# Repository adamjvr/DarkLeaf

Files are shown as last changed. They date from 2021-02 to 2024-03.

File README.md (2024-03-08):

# DarkLeaf
Adafruit Feather style board for the STM32WB5MMGH6TR 2G RF Module

Quick Specs:
- STM32WB5MMGH6TR 2G RF Module
- Adafruit Feather pinout and formfactor
- ARM Cortex M Debug Port
- USB C Connector For DFU Flashing (USB 2.0 interface)
- LiPO powered w/ onboard 3.3V LDO Regulator
- Can be powered directly by 3.3V when breadboarded

KiCAD 2D PCB Render 
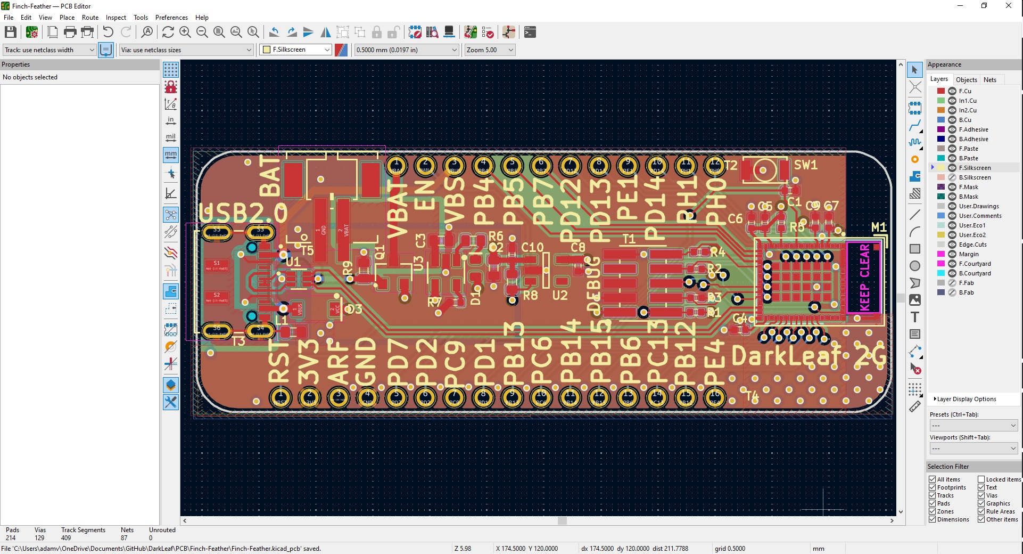
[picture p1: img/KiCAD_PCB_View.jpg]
PCB Render


3D KiCAD PCB Renders 
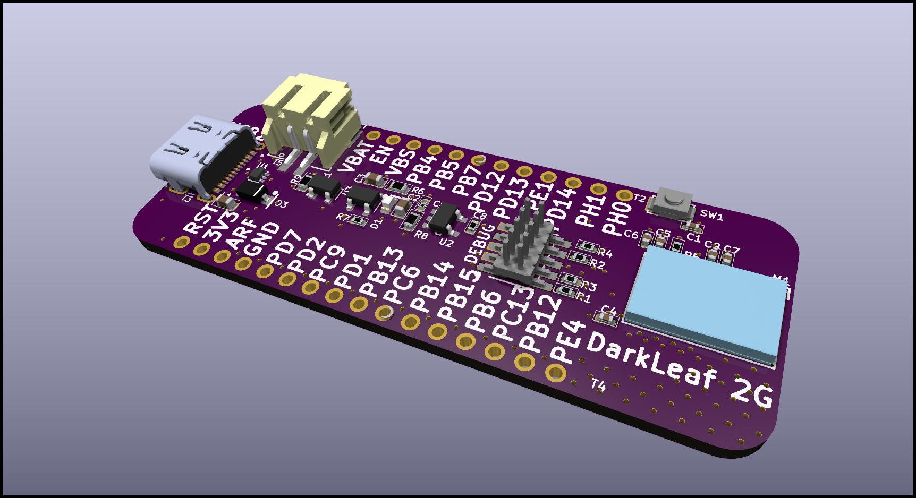
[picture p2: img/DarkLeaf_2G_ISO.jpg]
ISO Render


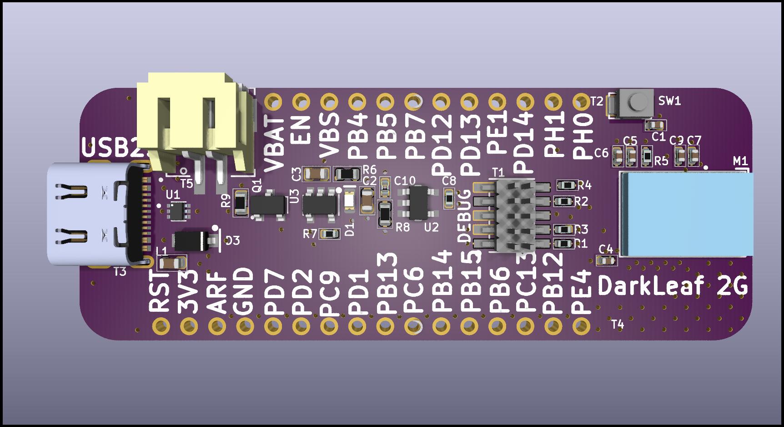
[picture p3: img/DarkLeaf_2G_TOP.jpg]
Top Render


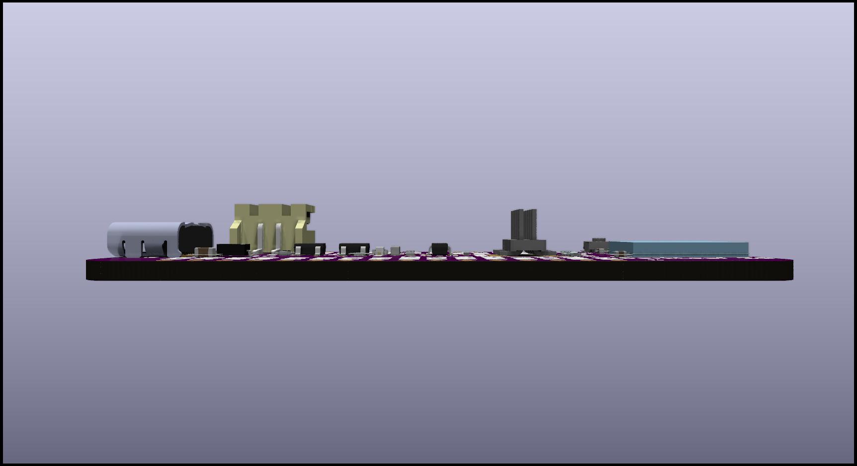
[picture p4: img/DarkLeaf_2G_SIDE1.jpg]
Side Render


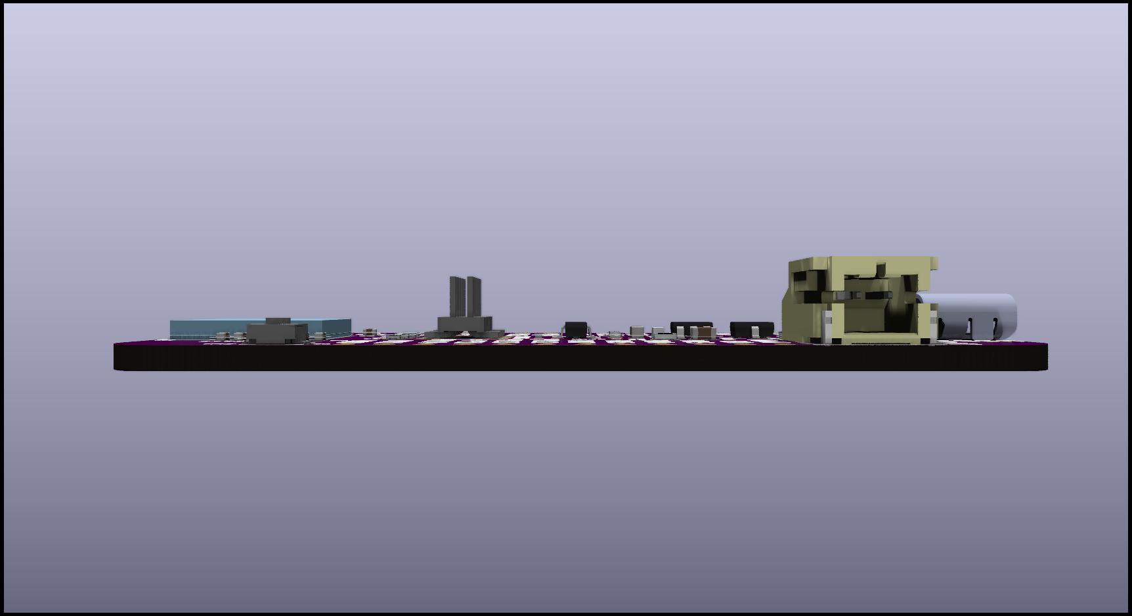
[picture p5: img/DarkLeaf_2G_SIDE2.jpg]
Side Render


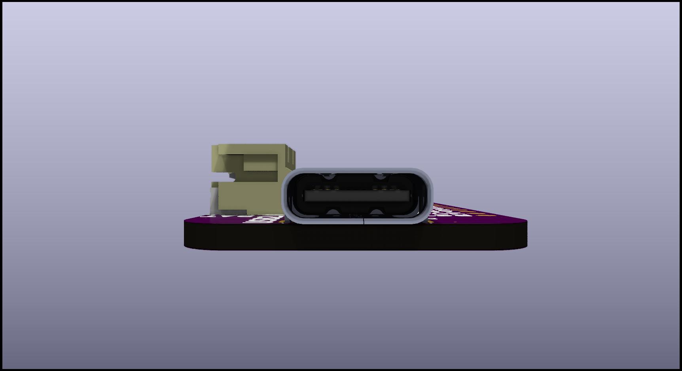
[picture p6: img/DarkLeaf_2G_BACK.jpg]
Back Render


Prototype made by OSHPark.com 
OSHPARK Fab}

Released Under CERN Open Hardware License Version 2

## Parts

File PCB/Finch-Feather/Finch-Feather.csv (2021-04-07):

Reference | Quantity | Value | Footprint | Datasheet | Cost QTY: 1 | Cost QTY: 1000 | Cost QTY: 10000 | Cost QTY: 2500 | Cost QTY: 5000 | Date Created | Date Modified | Description | Designer | Height | Lead-Free ? | MFR | MFR# | Management_ID | Mounting | Package | Pin Count # | RoHS Levels | Status | Tolerance | Type | Vendor | Vendor # | Voltage | _Value_
C1 C4 C5 C6 C7 C8 C9 C10 | 8 | C0402C104K9PACTU | AVR-KiCAD-Lib-Resistors:R0402 | https://content.kemet.com/datasheets/KEM_C1006_X5R_SMD.pdf | 0.10000 | 0.01139 | 0.00756 | 0.01035 | 0.00952 | 12/7/2019 | 12/7/2019 | 0.1µF ±10% 6.3V Ceramic Capacitor X5R 0402 (1005 Metric) | AVR | 0.55mm | Yes | KEMET | C0402C104K9PACTU | * | SMT | 0402 | 2 | 1 | Active | 10% | Ceramic Cap | Digikey | 399-3026-6-ND | 6.3V | 0.1uF
C2 C3 | 2 | C0603C475K9PACTU | AVR-KiCAD-Lib-Capacitors:C0603 | https://content.kemet.com/datasheets/KEM_C1006_X5R_SMD.pdf | 0.17000 | 0.03280 | 0.02260 | * | 0.02430 | 12/6/2019 | 12/6/2019 | 4.7µF ±10% 6.3V Ceramic Capacitor X5R 0603 (1608 Metric) | AVR | 0.9mm | Yes | KEMET | C0603C475K9PACTU | * | SMT | 0603 | 2 | 1 | Active | 10% | Ceramic Cap | Digikey | 399-3482-1-ND | 6.3V | 4.7uF X5R
D1 | 1 | LTST-C194TBKT | AVR-KiCAD-Lib-Diodes:LED0603 | http://optoelectronics.liteon.com/upload/download/DS22-2010-0025/LTST-C194TBKT.PDF | 0.42000 | 0.07797 | 0.05424 | * | 0.06102 | 3/1/2020 | 3/1/2020 | Blue 468nm LED Indication - Discrete 3.3V 0603 (1608 Metric) | AVR | 0.45mm | Yes | Lite-On Inc. | LTST-C194TBKT | * | SMT | 0603 | 2 | 1 | Active | * | Blue LED Colorless | Digikey | 160-1837-2-ND | 3.3V | Blue LED
D3 | 1 | MBR0540T1G | AVR-KiCAD-Lib-Diodes:D_SOD-123 | https://www.onsemi.com/pub/Collateral/MBR0540T1-D.PDF | 0.37000 | 0.07191 | * | * | * | 7/31/2020 | 7/31/2020 | Diode Schottky 40V 500mA Surface Mount SOD-123 | AVR | 1.17mm | Yes | ON Semiconductor | MBR0540T1G | * | SMT | SOD-123 | 2 | 1 | Active | * | TVS Diode | Digikey | MBR0540T1GOSTR-ND | 40V | MBR0540T1G
H1 H2 H4 | 3 | 2.54mm_PLT_Hole | AVR-KiCAD-Lib-Holes_Fasteners:2.54mm_PLT_Hole |  | * | * | * | * | * | * | * | * | * | * | * | * | * | * | * | * | * | * | * | * | * | * | * | * | 2.54mm Hole
L1 | 1 | MI0603K300R-10 | AVR-KiCAD-Lib-Inductors:MI0603K300R-10 | https://www.laird.com/sites/default/files/2018-11/Catalog_EMI%20FILTERING%20RF%200717.pdf | 0.16000 | 0.04313 | * | * | * | 6/16/2020 | 6/16/2020 | 30 Ohms @ 100MHz 1 Power Line Ferrite Bead 0603 (1608 Metric) 1.5A 90mOhm | AVR | 0.95mm | Yes | Laird-Signal Integrity Products | MI0603K300R-10 | * | SMT | 0603 | 2 | 1 | Active | * | Ferrite Bead | Digikey | 240-2373-1-ND | * | MI0603K300R-10
M1 | 1 | STM32WB5MMGH6TR | AVR-KiCAD-Lib-Modules:STM32WB5MMGH6TR | https://www.st.com/resource/en/datasheet/stm32wb5mmg.pdf | 12.98000 | 9.01250 | * | * | * | 2/8/2021 | 2/8/2021 | 802.15.4, Bluetooth Bluetooth v5.0, Thread, Zigbee® Transceiver Module 2.4GHz Integrated, Chip Surface Mount | AVR | 1.382mm | Yes | STMicroelectronics | STM32WB5MMGH6TR | * | SMT | * | 86 | 1 | Active | * | RF and MCU Integrated Module | Digikey | 497-STM32WB5MMGH6TR-ND | 1.71-3.6V | STM32WB5MMGH6TR
Q1 | 1 | DMP3125L-7 | growbox-KiCAD-Transistors:SOT-23 | https://www.diodes.com/assets/Datasheets/DMP3125L.pdf | 0.46000 | 0.09759 | 0.07624 | * | 0.08324 | 3/1/2020 | 3/1/2020 | P-Channel 30V 2.5A (Ta) 650mW (Ta) Surface Mount SOT-23 | AVR | 1.10mm | Yes | Diodes Incorporated | DMP3125L-7 | * | SMT | SOT23 | 3 | 1 | Active | * | P-Channel MOSFET | Digikey | DMP3125L-7DICT-ND | 20V | DMP3125L-7
R1 R2 R3 R4 R5 | 5 | RC0402FR-0710KL | AVR-KiCAD-Lib-Resistors:R0402 | https://www.yageo.com/upload/media/product/productsearch/datasheet/rchip/PYu-RC_Group_51_RoHS_L_10.pdf | 0.10000 | 0.00289 | * | 0.00251 | 0.00207 | 12/11/2019 | 12/11/2019 | 10 kOhms ±1% 0.063W, 1/16W Chip Resistor 0402 (1005 Metric) Moisture Resistant Thick Film | AVR | 0.4mm | Yes | Yageo | RC0402FR-0710KL | * | SMT | 0402 | 2 | 1 | Active | 1% | Thick FIlm Resistor | Digikey | 311-10.0KLRCT-ND | * | 10K
R6 | 1 | RC0603FR-07470RL | AVR-KiCAD-Lib-Resistors:R0603 |  | 0.100 | 0.00476 | * | 0.00418 | * | 4/23/2019 | 4/23/2019 | RES SMD 470 OHM 1% 1/10W 0603 | AVR | 0.55mm | Yes | Yageo | RC0603FR-07470RL | * | SMT | 0603 | 2 | 1 | Active | 1% | SMT Chip Resistor | Digikey | 311-470HRCT-ND | * | 470r
R7 | 1 | RC0402FR-072KL | AVR-KiCAD-Lib-Resistors:R0402 | https://www.yageo.com/upload/media/product/productsearch/datasheet/rchip/PYu-RC_Group_51_RoHS_L_10.pdf | 0.10000 | 0.00289 | 0.00163 | 0.00251 | 0.00207 | 7/6/2020 | 7/6/2020 | 2 kOhms ±1% 0.063W, 1/16W Chip Resistor 0402 (1005 Metric) Moisture Resistant Thick Film | AVR | 0.4mm | Yes | Yageo | RC0402FR-072KL | * | SMT | 0402 | 2 | 1 | Active | 1% | Resistor | Digikey | 311-2KLRCT-ND | * | 2K
R8 R9 | 2 | RC0603FR-07100KL | AVR-KiCAD-Lib-Resistors:R0603 |  | 0.10 | 0.00476 | * | 0.00418 | * | 4/23/2019 | 4/23/2019 | RES SMD 100K OHM 1% 1/10W 0603 | AVR | 0.55mm | Yes | Yageo | RC0603FR-07100KL | * | SMT | 0603 | 2 | 1 | Active | 1% | SMT Chip Resistor | Digikey | 311-100KHRCT-ND | * | 100K
SW1 | 1 | B3U-1000P | AVR-KiCAD-Lib-Mech-Switches:B3U-1000P | https://omronfs.omron.com/en_US/ecb/products/pdf/en-b3u.pdf | 0.98000 | 0.59822 | * | * | * | 6/15/2020 | 6/15/2020 | Tactile Switch SPST-NO Top Actuated Surface Mount | AVR | 1.6mm | Yes | Omron Electronics Inc-EMC Div | B3U-1000P | * | SMT | Proprietary | 2 | 1 | Active | * | Switch | Digikey | SW1020CT-ND | * | B3U-1000P
T1 | 1 | 20021121-00010C4LF | AVR-KiCAD-Lib-Connectors:20021121-00010C4LF | https://cdn.amphenol-icc.com/media/wysiwyg/files/drawing/20021121.pdf | 0.87000 | * | * | * | * | 6/16/2020 | 6/16/2020 | CONN HEADER SMD 10POS 1.27MM | AVR | 5.5mm | Yes | Amphenol ICC (FCI) | 20021121-00010C4LF | * | SMT | * | 10 | 1 | Active | * | SMT Pin Header | Digikey | 609-3695-1-ND | * | 20021121-00010C4LF
T2 | 1 | TSW-112-07-G-S | AVR-KiCAD-Lib-Connectors:SAMTEC-TSW-112-07-X-S | http://suddendocs.samtec.com/catalog_english/tsw_th.pdf | 1.29000 | * | * | * | * | 2/13/2021 | 2/13/2021 | Connector Header Through Hole 12 position 0.100 (2.54mm)" | AVR | 11.8mm | Yes | Samtec Inc. | TSW-112-07-G-S | * | ThroughHole | * | 12 | 1 | Active | * | Pin Header | Digikey | SAM1029-12-ND | * | TSW-112-07-G-S
T3 | 1 | DX07S016JA1R1500 | AVR-KiCAD-Lib-Connectors:JAE_DX07S016JA1R1500 | https://www.jae.com/direct/topics/topics_file_download/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 | 1.51000 | 0.81200 | * | * | * | 2/10/2021 | 2/10/2021 | USB-C (USB TYPE-C) USB 2.0 Receptacle Connector 24 (16+8 Dummy) Position Surface Mount, Right Angle; Through Hole | AVR | 3.2mm | Yes | JAE Electronics | DX07S016JA1R1500 | * | Throughhole & SMT | * | 16 | 1 | Active | * | USB-C | Digikey | 670-DX07S016JA1R1500TR-ND | 20V | DX07S016JA1R1500
T4 | 1 | TSW-116-07-L-S | AVR-KiCAD-Lib-Connectors:SAMTEC-TSW-116-07-X-S | http://suddendocs.samtec.com/catalog_english/tsw_th.pdf | 1.38000 | 0.76500 | 0.66300 | * | 0.67830 | 2/13/2021 | 2/13/2021 | Connector Header Through Hole 16 position 0.100 (2.54mm)" | AVR | 11.8mm | Yes | Samtec Inc. | TSW-116-07-L-S | * | ThroughHole | * | 16 | 1 | Active | * | Pin Header | Digikey | TSW-116-07-L-S-ND | * | TSW-116-07-L-S
T5 | 1 | S2B-PH-SM4-TB(LF)(SN) | AVR-KiCAD-Lib-Connectors:B2B-PH-SM4-TB(LF)(SN) | https://www.jst-mfg.com/product/pdf/eng/ePH.pdf | 0.53000 | 0.27353 | 0.22380 | * | 0.24037 | 2/19/2021 | 2/19/2021 | Connector Header Surface Mount, Right Angle 2 position 0.079 (2.00mm)" | AVR | 5.51mm | Yes | JST Sales America Inc. | S2B-PH-SM4-TB(LF)(SN) | * | SMT | * | 2 | 1 | Active | * | JST Connector | Digikey | 455-1749-2-ND | 94V | S2B-PH-SM4-TB(LF)(SN)
U1 | 1 | USBLC6-2P6 | AVR-KiCAD-Lib-ICs:SOT50P160X60-6N | https://www.st.com/content/ccc/resource/technical/document/datasheet/06/1d/48/9c/6c/20/4a/b2/CD00050750.pdf/files/CD00050750.pdf/jcr:content/translations/en.C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 | 0.57000 | 0.24640 | * | * | * | 2/13/2021 | 2/13/2021 | 17V Clamp 5A (8/20µs) Ipp Tvs Diode Surface Mount SOT-666 | AVR | * | Yes | STMicroelectronics | USBLC6-2P6 | * | SMT | SOT666 | 6 | 1 | Active | * | ESD Supressor USB | Digikey | 497-5026-2-ND | 17V Clamping | USBLC6-2P6
U2 | 1 | TLV75533PDBVR | AVR-KiCAD-Lib-ICs:TLV75533PDBVR | https://www.ti.com/lit/ds/symlink/tlv755p.pdf?HQS=dis-dk-null-digikeymode-dsf-pf-null-wwe&ts=1613655963783 | 0.42000 | 0.14787 | * | * | * | 2/18/2021 | 2/18/2021 | Linear Voltage Regulator IC Positive Fixed 1 Output 500mA SOT-23-5 | AVR | * | Yes | Texas Instruments | TLV75533PDBVR | * | SMT | * | 5 | 1 | Active | * | LDO | Digikey | 296-50411-2-ND | 3.3V 500MA | TLV75533PDBVR
U3 | 1 | MCP73831T-2ACI_OT | AVR-KiCAD-Lib-ICs:SOT-23-5 | https://ww1.microchip.com/downloads/en/DeviceDoc/MCP73831-Family-Data-Sheet-DS20001984H.pdf | 0.59 | * | * | * | * | 2/20/2021 | 2/20/2021 | Charger IC Lithium Ion/Polymer SOT-23-5 | AVR | 1.3mm | Yes | Microchip Technology | MCP73831T-2ACI/OT | * | SMT | SOT23-5 | 5 | 1 | Active | * | LiPo charger | Mouser | 579-MCP73831T-2ACIOT | * | MCP73831T-2ACI/OT

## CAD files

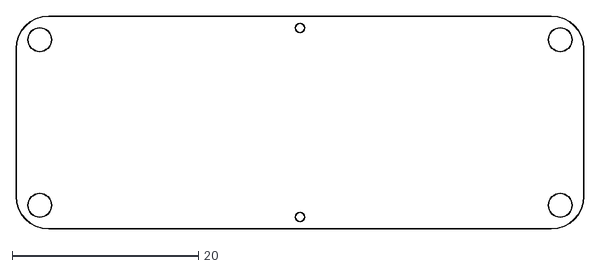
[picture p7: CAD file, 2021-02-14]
PCB/Finch-Feather/Feather_OUTLIINE.dxf
61.0 x 22.9

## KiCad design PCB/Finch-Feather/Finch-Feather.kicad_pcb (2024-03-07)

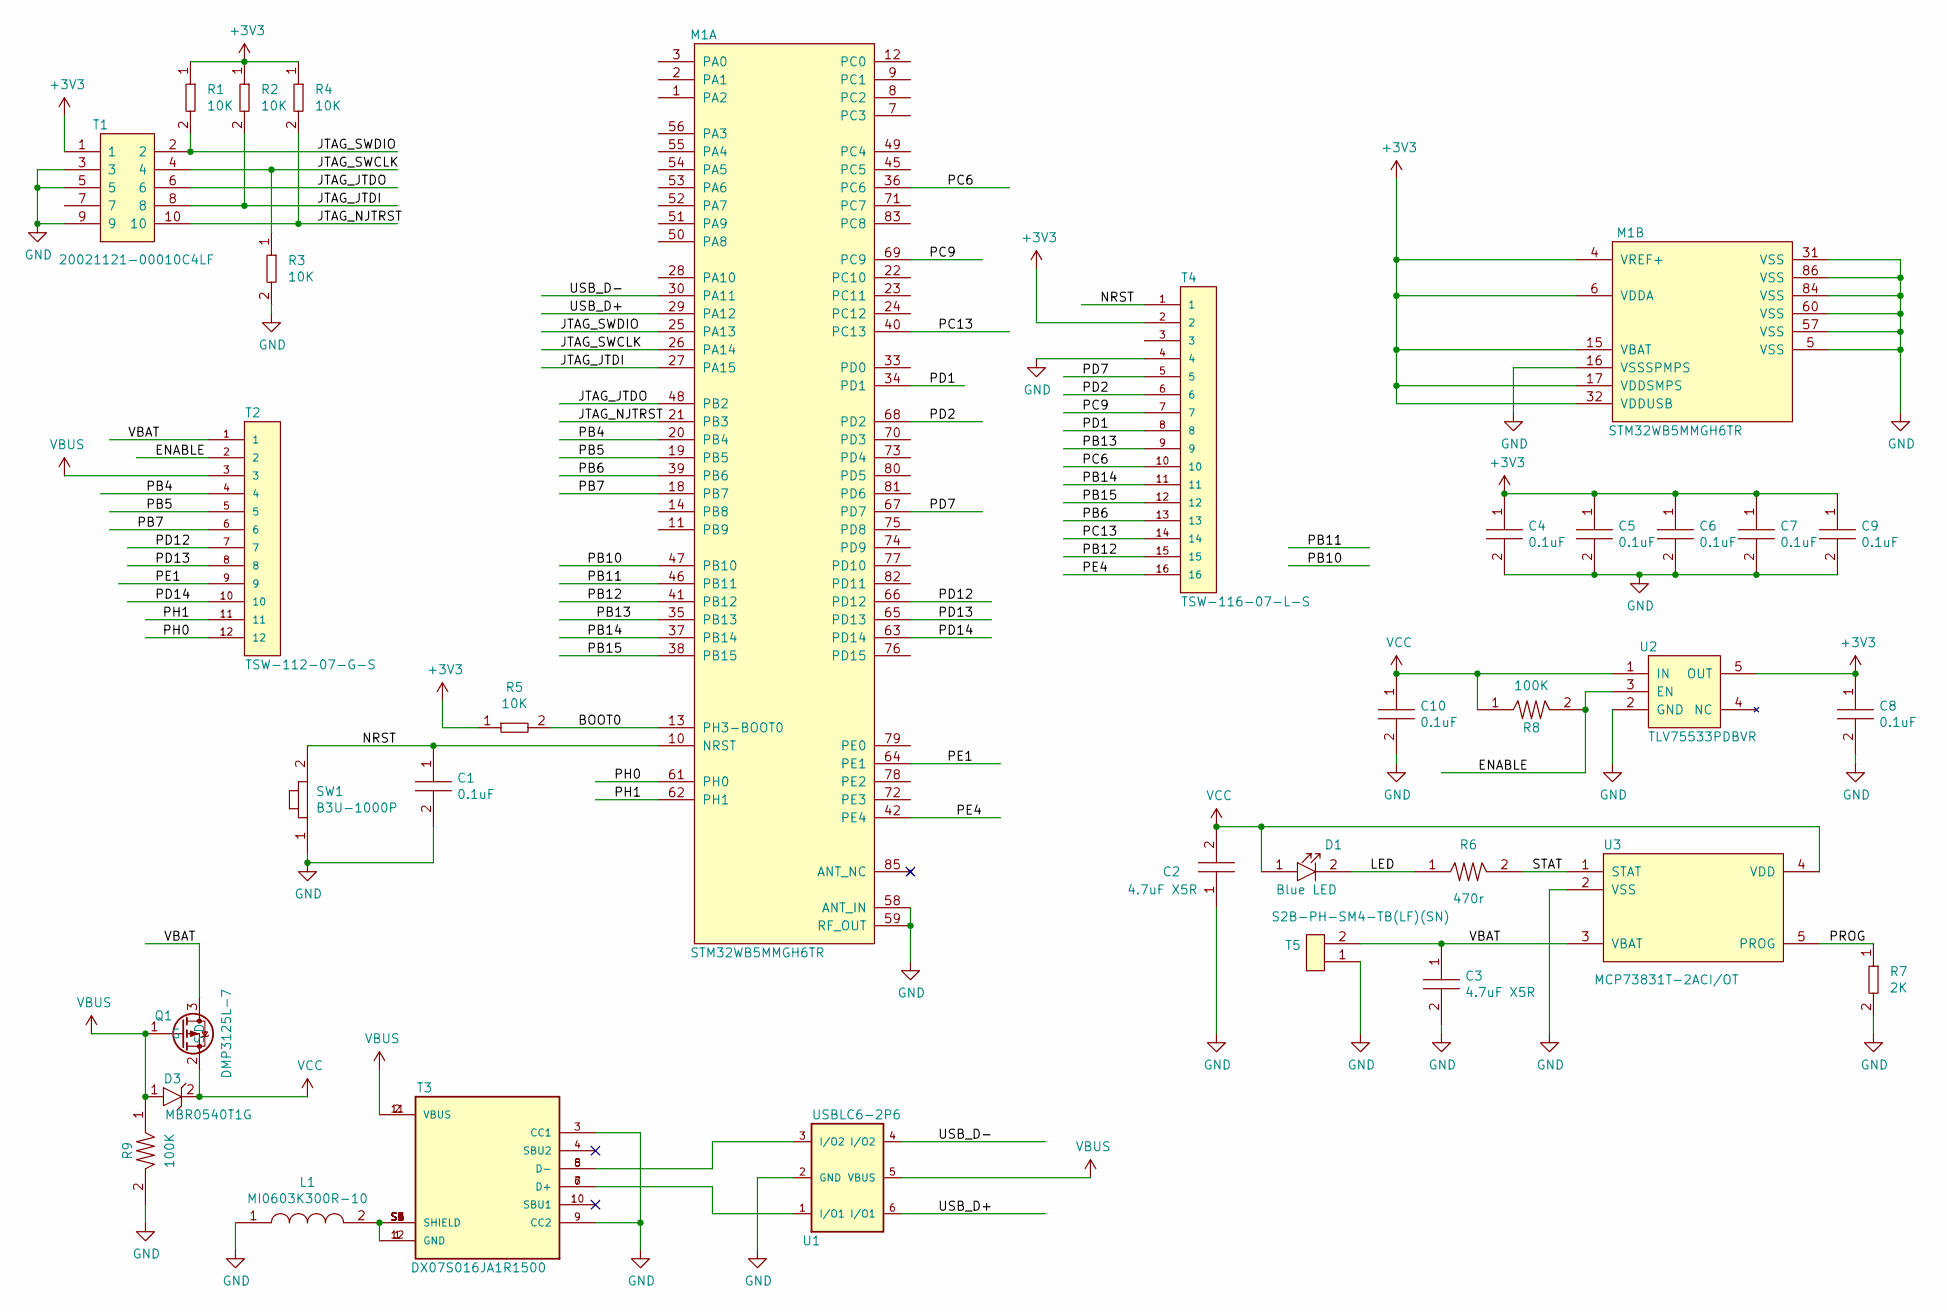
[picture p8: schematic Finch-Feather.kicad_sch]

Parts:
C1, C4, C5, C6, C7, C8, C9, C10: C0402C104K9PACTU; R0402; Tolerance 10%; Voltage 6.3V; MFR# C0402C104K9PACTU
C2, C3: C0603C475K9PACTU; C0603; Tolerance 10%; Voltage 6.3V; MFR# C0603C475K9PACTU
D1: LTST-C194TBKT; LED0603; Tolerance *; Voltage 3.3V; MFR# LTST-C194TBKT
D3: MBR0540T1G; D_SOD-123; Tolerance *; Voltage 40V; MFR# MBR0540T1G
L1: MI0603K300R-10; Tolerance *; Voltage *; MFR# MI0603K300R-10
M1: STM32WB5MMGH6TR; Tolerance *; Voltage 1.71-3.6V; MFR# STM32WB5MMGH6TR
Q1: DMP3125L-7; SOT-23; Tolerance *; Voltage 20V; MFR# DMP3125L-7
R1, R2, R3, R4, R5: RC0402FR-0710KL; R0402; Tolerance 1%; Voltage *; MFR# RC0402FR-0710KL
R6: RC0603FR-07470RL; R0603; Tolerance 1%; Voltage *; MFR# RC0603FR-07470RL
R7: RC0402FR-072KL; R0402; Tolerance 1%; Voltage *; MFR# RC0402FR-072KL
R8, R9: RC0603FR-07100KL; R0603; Tolerance 1%; Voltage *; MFR# RC0603FR-07100KL
SW1: B3U-1000P; Tolerance *; Voltage *; MFR# B3U-1000P
T1: 20021121-00010C4LF; Tolerance *; Voltage *; MFR# 20021121-00010C4LF
T2: TSW-112-07-G-S; SAMTEC-TSW-112-07-X-S; Tolerance *; Voltage *; MFR# TSW-112-07-G-S
T3: DX07S016JA1R1500; JAE_DX07S016JA1R1500; Tolerance *; Voltage 20V; MFR# DX07S016JA1R1500
T4: TSW-116-07-L-S; SAMTEC-TSW-116-07-X-S; Tolerance *; Voltage *; MFR# TSW-116-07-L-S
T5: S2B-PH-SM4-TB(LF)(SN); B2B-PH-SM4-TB(LF)(SN); Tolerance *; Voltage 94V; MFR# S2B-PH-SM4-TB(LF)(SN)
U1: USBLC6-2P6; SOT50P160X60-6N; Tolerance *; Voltage 17V Clamping; MFR# USBLC6-2P6
U2: TLV75533PDBVR; Tolerance *; Voltage 3.3V 500MA; MFR# TLV75533PDBVR
U3: MCP73831T-2ACI_OT; SOT-23-5; Tolerance *; Voltage *; MFR# MCP73831T-2ACI/OT

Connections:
+3V3: C4.1, C5.1, C6.1, C7.1, C8.1, C9.1, M1.4 (VREF+), M1.6 (VDDA), M1.15 (VBAT), M1.17 (VDDSMPS), M1.32 (VDDUSB), R1.1, R2.1, R4.1, R5.1, T1.1, T4.2, U2.5 (OUT)
/BOOT0: M1.13 (PH3-BOOT0), R5.2
/ENABLE: R8.2, T2.2, U2.3 (EN)
/JTAG_JTDI: M1.27 (PA15), R2.2, T1.8
/JTAG_JTDO: M1.48 (PB2), T1.6
/JTAG_NJTRST: M1.21 (PB3), R4.2, T1.10
/JTAG_SWCLK: M1.26 (PA14), R3.1, T1.4
/JTAG_SWDIO: M1.25 (PA13), R1.2, T1.2
/LED: D1.2, R6.1
/NRST: C1.1, M1.10 (NRST), SW1.2, T4.1
/PB4: M1.20 (PB4), T2.4
/PB5: M1.19 (PB5), T2.5
/PB6: M1.39 (PB6), T4.13
/PB7: M1.18 (PB7), T2.6
/PB10: M1.47 (PB10)
/PB11: M1.46 (PB11)
/PB12: M1.41 (PB12), T4.15
/PB13: M1.35 (PB13), T4.9
/PB14: M1.37 (PB14), T4.11
/PB15: M1.38 (PB15), T4.12
/PC6: M1.36 (PC6), T4.10
/PC9: M1.69 (PC9), T4.7
/PC13: M1.40 (PC13), T4.14
/PD1: M1.34 (PD1), T4.8
/PD2: M1.68 (PD2), T4.6
/PD7: M1.67 (PD7), T4.5
/PD12: M1.66 (PD12), T2.7
/PD13: M1.65 (PD13), T2.8
/PD14: M1.63 (PD14), T2.10
/PE1: M1.64 (PE1), T2.9
/PE4: M1.42 (PE4), T4.16
/PH0: M1.61 (PH0), T2.12
/PH1: M1.62 (PH1), T2.11
/PROG: R7.1, U3.5 (PROG)
/STAT: R6.2, U3.1 (STAT)
/USB_D+: M1.29 (PA12), U1.6 (I/O1)
/USB_D-: M1.30 (PA11), U1.4 (I/O2)
/VBAT: C3.1, Q1.3 (D), T2.1, T5.2, U3.3 (VBAT)
GND: C1.2, C2.1, C3.2, C4.2, C5.2, C6.2, C7.2, C8.2, C9.2, C10.2, L1.1, M1.5 (VSS), M1.16 (VSSSPMPS), M1.31 (VSS), M1.57 (VSS), M1.58 (ANT_IN), M1.59 (RF_OUT), M1.60 (VSS), M1.84 (VSS), M1.86 (VSS), R3.2, R7.2, R9.2, SW1.1, T1.3, T1.5, T1.9, T3.3 (CC1), T3.9 (CC2), T4.4, T5.1, U1.2 (GND), U2.2 (GND), U3.2 (VSS)
unnamed: L1.2, T3.1 (GND), T3.12 (GND), T3.S1 (SHIELD), T3.S2 (SHIELD), T3.S3 (SHIELD), T3.S4 (SHIELD), T3.S5 (SHIELD), T3.S6 (SHIELD)
unnamed: T3.5 (D-), T3.8 (D-), U1.3 (I/O2)
unnamed: T3.6 (D+), T3.7 (D+), U1.1 (I/O1)
VBUS: D3.1, Q1.1 (G), R9.1, T2.3, T3.2 (VBUS), T3.11 (VBUS), U1.5 (VBUS)
VCC: C2.2, C10.1, D1.1, D3.2, Q1.2 (S), R8.1, U2.1 (IN), U3.4 (VDD)

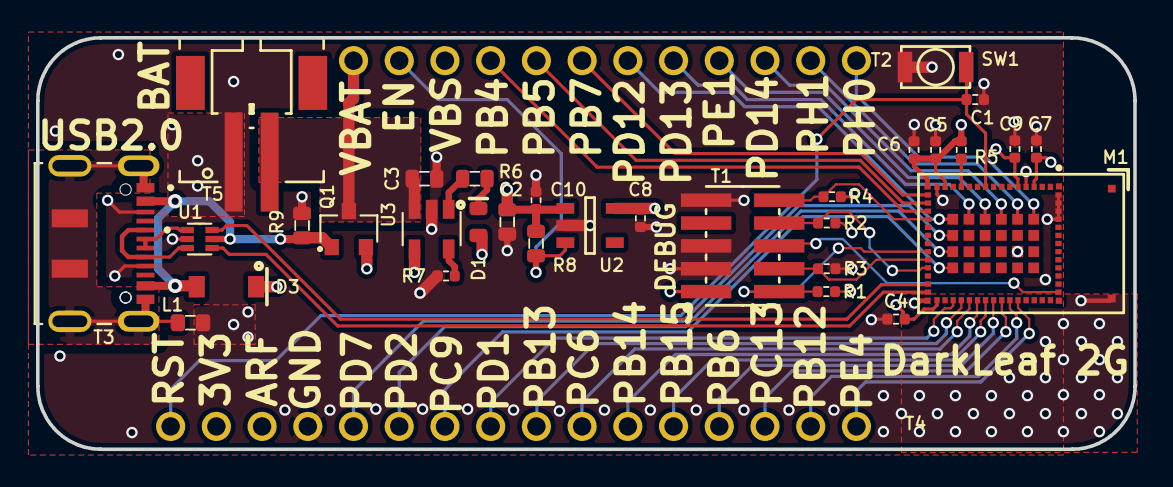
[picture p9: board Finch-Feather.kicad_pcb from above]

Board: 4 copper layers, 61.0 x 22.9 mm, 33 parts (0 on the bottom side), 42 nets.

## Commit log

2021-02-14 Schematic
    First pass on schematic, still needs a few things before annotation
    [Feather_OUTLIINE.dxf, Finch-Feather.kicad_pcb, Finch-Feather.sch]
2021-02-14 PCB
    PCB started, next step figuring out which pins on module to use
    [Finch-Feather.kicad_pcb, Finch-Feather.sch]
2021-02-15 PCB Near Finished
    Head signals wired to pins on module, power supply section and USB connector are next
    [Finch-Feather.kicad_pcb, Finch-Feather.sch]
2021-02-19 PCB Progress
    More progress on PCB design, made some tweaks and changes, implemented enable circuit.
    [Finch-Feather.kicad_pcb, Finch-Feather.sch]
2021-02-21 PCB pass COmplete
    First true pass of PCB fully complete, with new power switching circuit and regulator enable. Smaller packages selected for pretty much every IC previously used.
    [Finch-Feather.kicad_pcb, Finch-Feather.sch]
2021-02-22 Heavy PCB Rework
    Reworked the Portion of the PCB around the ST RF module, signals re-chosen for 3 GPIOs to make the grounding conform more to the reference design recommendations.
    [Finch-Feather.kicad_pcb, Finch-Feather.sch]
2021-03-08 PCB changes
    Adjusted pours, next need to perfrom DRC, syncing for work
    [Finch-Feather.kicad_pcb]
2021-04-07 Prefab changes
    minor adjustments, removal of screw holes, and additional via stitching
    [Finch-Feather-B_Cu.gbr, Finch-Feather-B_Mask.gbr, Finch-Feather-B_Paste.gbr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]
2024-03-07 KiCAD Project Upadated and Images added
    Updated the KiCAD Project to the newest version, restored paths for 3D files for board components. Added 3D rendered images of the board.
    [Finch-Feather.kicad_pcb, Finch-Feather.kicad_sch]
